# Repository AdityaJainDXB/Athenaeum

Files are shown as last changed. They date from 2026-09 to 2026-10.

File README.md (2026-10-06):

# Athenaeum

Open-source e-ink reader that downloads free books from Archive.org over Wi-Fi, takes notes on what you read, and even serves as a tiny offline viewer for NASA's public data. All on a single custom circuit board.

---

The idea

Since public domain books are free, you can also access The Internet Archive and Open Library with millions of these. NASA has tons of open data too – images from missions, the Astronomy Picture of the Day archive, the Artemis mission logs. But to be used, you need an internet connection, which isn't always available – weak school WiFi, no data plan, off the grid.

The Athenaeum, then, is a little battery powered piece of kit that solves this problem: when you're online, just sync up Athenaeum and it will take all of your books, your notes and a smattering of NASA's free open data with you as far as you go. And it's a multiple app device, too: it's designed as a little plug-in gadget and is capable of running multiple applications.

All of this – schematic, pcb and firmware – was really designed from scratch and is open source.

# It's basically a little computer with an e-ink display

The book reader is the first feature you get, not the only one it has. If you strip it away you end up with an ESP32-S3, a large e-ink display, Wi-Fi, an SD card, and buttons. The firmware is an app launcher, so creating a new feature (a flash card reader, a weather log, whatever) is a change to the firmware, not the design of the board. If you copy this board to create another project, you've already done the electronics.

What it does right now

1. Searches and downloads books from Archive.org / Open Library via Wi-Fi

- Reads them offline on the e-ink display (done) - exists a local library on microSD Would you like to comment? Post your comment or leave your feedback below: Name (required): Email (will not be published) (required): Comments: Submit" /> Submit DisableI want this answerAnswered.
- Allows you to save/flag notes associated with a book and page
- Features a "Space" app that takes NASA's Astronomy Picture of the Day for offline use
- Utilizes a rechargeable battery, charged via USB-C

Actually still on the to-do list that don't require phantom and name scanning: full EPUB rendering (currently just outputs plain text, which is what Archive.org's OCR files are, so this one is already working end to end for many books), APOD image in lieu of just the photo's caption, and a real scrollable book list rather than just "pop" the first file. All in firmware/README.md, as always.

The hardware

- ESP32-S3-WROOM-1 – Wi-Fi, USB native, everything runs on it
- Waveshare 7.5" e-Paper panel (800480), with a Waveshare Driver HAT plus a simple 8-pin header - we couldn't use the raw e-ink panels because they use an undocumented FPC connector, which makes designing a board around non-viable; this was the sane middle ground: still a fully custom PCB, just not re-inventing the display driver electronics as well
- MCP73831: Solves the USB power delivery problem by charging a single cell LiPo from a USB-C power source
- TLV70233 regulator - low standby current because this thing is going to need to sit in somebody's bag for weeks between charges
- microSD for the actual book/note storage
- 7 buttons: 5 for navigation, plus reset, and boot

Enclosure? None (this is designed to be used a bare board, with all the exposed components). The board outline is rounded off to prevent sharp edges, but there is no case concealing it.

Complete schematic & board files are located in /hardware.

# Pin map

| Signal | GPIO | | Signal | GPIO |

|---|---|---|---|---|

| EPD_CS | 10 | | Button: Up | 4 |

" /> Button: Up Button: Down | EPD_DC | 11 | | Button: Up | 5 |

| EPD_RST | 12 | | Button: Choose | 6 |

| EPD_BUSY | 13 | | Button: back | 7 |

Button: Menu 8 EPD_SCK 14

| EPD_MOSI | 15 | | SD CS | 16 |

| | | | SD MISO | 17 |

(SPI clock and MOSI are the same for display and SD card - separate CS lines are used for each, that is the correct design, not a shortcut.)

Repo layout

``

athenaeum/

hardware/

kicad/ KiCad project - schematic + PCB

gerbers/ Manufacturing files for JLCPCB

BOM.csv All parts list, with LCSC part numbers

firmware/ ESP32-S3 firmware (PlatformIO)

docs/ Build guide

`

Building one yourself

1. Upload the following data to the JLCPCB PCB Assembling: hardware/gerbers/ and hardware/BOM.csv
2. Flash the firmware - see firmware/README.md.
3. Insert the Waveshare Driver HAT + panel into the 8-pin header (J2).

Full walkthrough: docs/BUILDGUIDE.md.

Where things stand

- [x] Schematic - designed and verified
- [x] PCB - routed, DRC clean
- [x] Gerbers/BOM exported, ready for JLCPCB
- [x] Firmware - app launcher, Wi-Fi + Archive.org search/download, plain-text reading,
Scrollable book browser real on-device note-taking Space app
- [ ] EPUB parsing (accepts only plaintext atm)
- [ ] APOD image rendering (This is just text now)

- [ ] Demo video

Firmware limitations, stated plainly

This is a real, working firmware skeleton, not a finished article - worth being upfront

About exactly what it does and doesn't do so far:

- No EPUB support as yet. It only supports plain .txt files. Which just happens to be quite a lot of files.
Read already, as Archive.org's OCR'd texts come as .txt search
Download browse read works end to end for many public-domain books. EPUB actual The end Works The Bookshelf So when I teach my readers will lead to the works I read, in their works just to pass a great conversation, or even for passes… because I read in them.
(unzipping the container, parsing XHTML/CSS on-device) is an additional, substantial chunk.
 Of work, not yet started.
- All NASA APOD is text-only. It retrieves and displays the current day's title and date as well as the day's.
Explanation – but it is not the real photo. Rendering a true image on e-ink is
Download, JPEG-decoding, scaling, and dithering the image to 1-bit - has not even started.
- Character by character (single entry) picker, because there's no keyboard - it
Works, but writing anything that is of any length is slow. So a reasonably fast input scheme is the next step in design
 step.
- It hasn't been assembled and run on real hardware. It was written with great care against
The right libraries and the actual pcb pinout and there was a build missing too(ESP32).
Environment that I could use to test it during the development of this repo. Expect a standard
First-build debugging pass (a library version mismatch, an exact display-panel class
(name to confirm)and not a guaranteed 'perfect' first flash.

Full detail in firmware/README.md`.

License

Hardware (schematic, PCB): CERN-OHL-S v2. Firmware: MIT.

Thanks to

Open source projects Inkplate, Flick Book for previous E-ink reader, Waveshare for their Driver HAT docs, and Archive.org / Open Library for maintaining an open API.

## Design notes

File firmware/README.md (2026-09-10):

# Firmware

ESP32-S3 firmware, built on the Arduino core via PlatformIO.

## Structure

```
firmware/
├── platformio.ini          Build config, board target, library dependencies
└── src/
    ├── config.h             Pin definitions (matches the PCB design) + Wi-Fi credentials
    ├── buttons.h             Debounced button reading (Up/Down/Select/Back/Menu)
    ├── display.h              GxEPD2 wrapper for the Waveshare 7.5" panel
    ├── sd_storage.h            microSD init + book/notes/config directory setup
    ├── book_browser.h           Scrollable list of books on the SD card
    ├── reader.h                 Plain-text book reader with pagination
    ├── text_entry.h              On-device character-picker text entry for notes
    ├── notes.h                    Per-book note/highlight storage (JSON on SD)
    ├── space.h                     NASA APOD viewer
    ├── net/archive_api.h            Archive.org search + plain-text download client
    └── main.cpp                     App launcher tying everything together
```

## Building

1. Install [PlatformIO](https://platformio.org/) (CLI or the VS Code extension).
2. Fill in your Wi-Fi credentials in `src/config.h` - it ships with placeholder
   text (`YOUR_WIFI_SSID` etc.), so Wi-Fi-dependent features won't work until
   you swap those for your real network details.
3. Get a free NASA API key at [api.nasa.gov](https://api.nasa.gov) and set it in
   `src/space.h` (the shared `DEMO_KEY` works for development but is rate-limited).
4. `pio run -t upload` - flashes over USB-C (native USB on the ESP32-S3, no
   separate programmer needed).

## What's implemented

- App launcher menu (Reader / Space / Notes / Wi-Fi Sync), navigated with the 5 nav buttons
- **Book browser** - scrolls through every `.txt` file on the SD card, not just the first one found
- Plain-text book reading with pagination, from SD card
- **Real note-taking** - an on-device character picker (Up/Down to change letter, Select to
  add it, Back to delete, Menu to save) so notes are actually typed text, not a placeholder string
- NASA APOD: fetches and displays today's title, date, and explanation text
- Archive.org search (by query) and plain-text download of a result to SD

## Known scope limits (honest, not hidden)

- **EPUB rendering isn't implemented.** The reader and browser both work with plain `.txt`
  files, which conveniently covers Archive.org's `_djvu.txt` OCR derivative used by the
  download client - so search -> download -> browse -> read works end to end for a lot of
  public-domain texts already. True EPUB support means unzipping the container and parsing
  XHTML/CSS on-device, a real chunk of work on its own, tracked as a follow-up.
- **APOD image rendering isn't implemented.** Currently shows the day's title, date, and
  explanation as text only. The actual photo needs JPEG decode + resize + dither-to-1-bit
  for the e-ink panel, also tracked as a follow-up.
- **Text entry is slow by design** - a single-character-at-a-time picker is the realistic
  option on a 5-button device with no keyboard. It works, but writing a long note takes a
  while; a faster input scheme (e.g. T9-style grouping) is a reasonable future improvement.

## A note on testing

This firmware was written and reasoned through carefully, but it has not been compiled or
run on real hardware as part of putting this repository together - there was no ESP32 or
build environment available to do that. Treat the first build as a normal first build:
expect to work through a handful of small compile issues (a library version mismatch, an
exact class name for your specific panel revision) rather than a flawless first flash.
The structure and logic are sound; the fine details of a first bring-up are still yours to
work through.

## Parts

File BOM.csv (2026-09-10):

Designator | Value | Footprint | LCSC Part | Description | Approx Unit Cost (USD) | Qty
U1 | ESP32-S3-WROOM-1 | RF_Module:ESP32-S3-WROOM-1 | C2913198 | ESP32-S3 Wi-Fi/BLE module 8MB flash | ~2.50 | 1
U2 | MCP73831-2-OT | Package_TO_SOT_SMD:SOT-23-5 | C424093 | LiPo linear charge management IC (4.2V) | ~0.15 | 1
U3 | TLV70233_SOT23-5 | Package_TO_SOT_SMD:SOT-23-5 | C110287 | 3.3V low-IQ LDO regulator | ~0.20 | 1
J1 | USB_C_Receptacle_USB2.0_14P | Connector_USB:USB_C_Receptacle_GCT_USB4085 |  | USB-C receptacle (power + data) | ~0.30 | 1
J2 | Conn_01x08 | Connector_PinHeader_2.54mm:PinHeader_1x08_P2.54mm_Vertical |  | 8-pin header to e-Paper Driver HAT | ~0.10 | 1
J3 | Micro_SD_Card_Det1 | Connector_Card:microSD_HC_Molex_47219-2001 |  | microSD card socket | ~0.40 | 1
BT1 | Battery_Cell | Connector_JST:JST_PH_S2B-PH-K_1x02_P2.00mm_Horizontal |  | JST-PH 2-pin battery connector | ~0.10 | 1
D1 | LED | LED_SMD:LED_0603_1608Metric |  | Charging status LED | ~0.02 | 1
C1 | 100nF | Capacitor_SMD:C_0603_1608Metric |  | Decoupling capacitor | ~0.01 | 1
C2 | 10uF | Capacitor_SMD:C_0603_1608Metric |  | Bulk decoupling capacitor | ~0.02 | 1
R1 | 10k | Resistor_SMD:R_0603_1608Metric |  | Boot (GPIO0) pull-up | ~0.01 | 1
R2 | 10k | Resistor_SMD:R_0603_1608Metric |  | Reset (EN) pull-up | ~0.01 | 1
R3 | 5.1k | Resistor_SMD:R_0603_1608Metric |  | USB-C CC1 pull-down | ~0.01 | 1
R4 | 5.1k | Resistor_SMD:R_0603_1608Metric |  | USB-C CC2 pull-down | ~0.01 | 1
R5 | 2k | Resistor_SMD:R_0603_1608Metric |  | Charge current set (PROG) | ~0.01 | 1
R6 | 1k | Resistor_SMD:R_0603_1608Metric |  | Status LED current limit | ~0.01 | 1
R7 | 10k | Resistor_SMD:R_0603_1608Metric |  | Button pull-up (Up) | ~0.01 | 1
R8 | 10k | Resistor_SMD:R_0603_1608Metric |  | Button pull-up (Down) | ~0.01 | 1
R9 | 10k | Resistor_SMD:R_0603_1608Metric |  | Button pull-up (Menu) | ~0.01 | 1
R10 | 10k | Resistor_SMD:R_0603_1608Metric |  | Button pull-up (Back) | ~0.01 | 1
R11 | 10k | Resistor_SMD:R_0603_1608Metric |  | Button pull-up (Select) | ~0.01 | 1
SW1 | SW_Push | Button_Switch_THT:SW_PUSH_6mm |  | Boot button | ~0.05 | 1
SW2 | SW_Push | Button_Switch_THT:SW_PUSH_6mm |  | Reset button | ~0.05 | 1
SW3 | SW_Push | Button_Switch_THT:SW_PUSH_6mm |  | Nav button: Up | ~0.05 | 1
SW4 | SW_Push | Button_Switch_THT:SW_PUSH_6mm |  | Nav button: Down | ~0.05 | 1
SW5 | SW_Push | Button_Switch_THT:SW_PUSH_6mm |  | Nav button: Menu | ~0.05 | 1
SW6 | SW_Push | Button_Switch_THT:SW_PUSH_6mm |  | Nav button: Back | ~0.05 | 1
SW7 | SW_Push | Button_Switch_THT:SW_PUSH_6mm |  | Nav button: Select | ~0.05 | 1
Off-board items (not part of PCB assembly order):
Item | Description | Approx Cost (USD) | Qty
Waveshare 7.5" e-Paper panel (800x480 mono) | Main display | ~35-45 | 1
Waveshare Universal e-Paper Driver HAT | FPC-to-header display adapter | ~10 | 1
Single-cell LiPo battery (JST-PH connector) | Power source - capacity TBD based on enclosure size | ~5-8 | 1
Note: unit costs are approximate JLCPCB/LCSC catalog estimates as of design time and should be
re-verified at checkout | since component pricing and stock fluctuate. PCB fabrication and assembly
service fees (setup | extended-part fees | shipping) are separate from per-component costs above.

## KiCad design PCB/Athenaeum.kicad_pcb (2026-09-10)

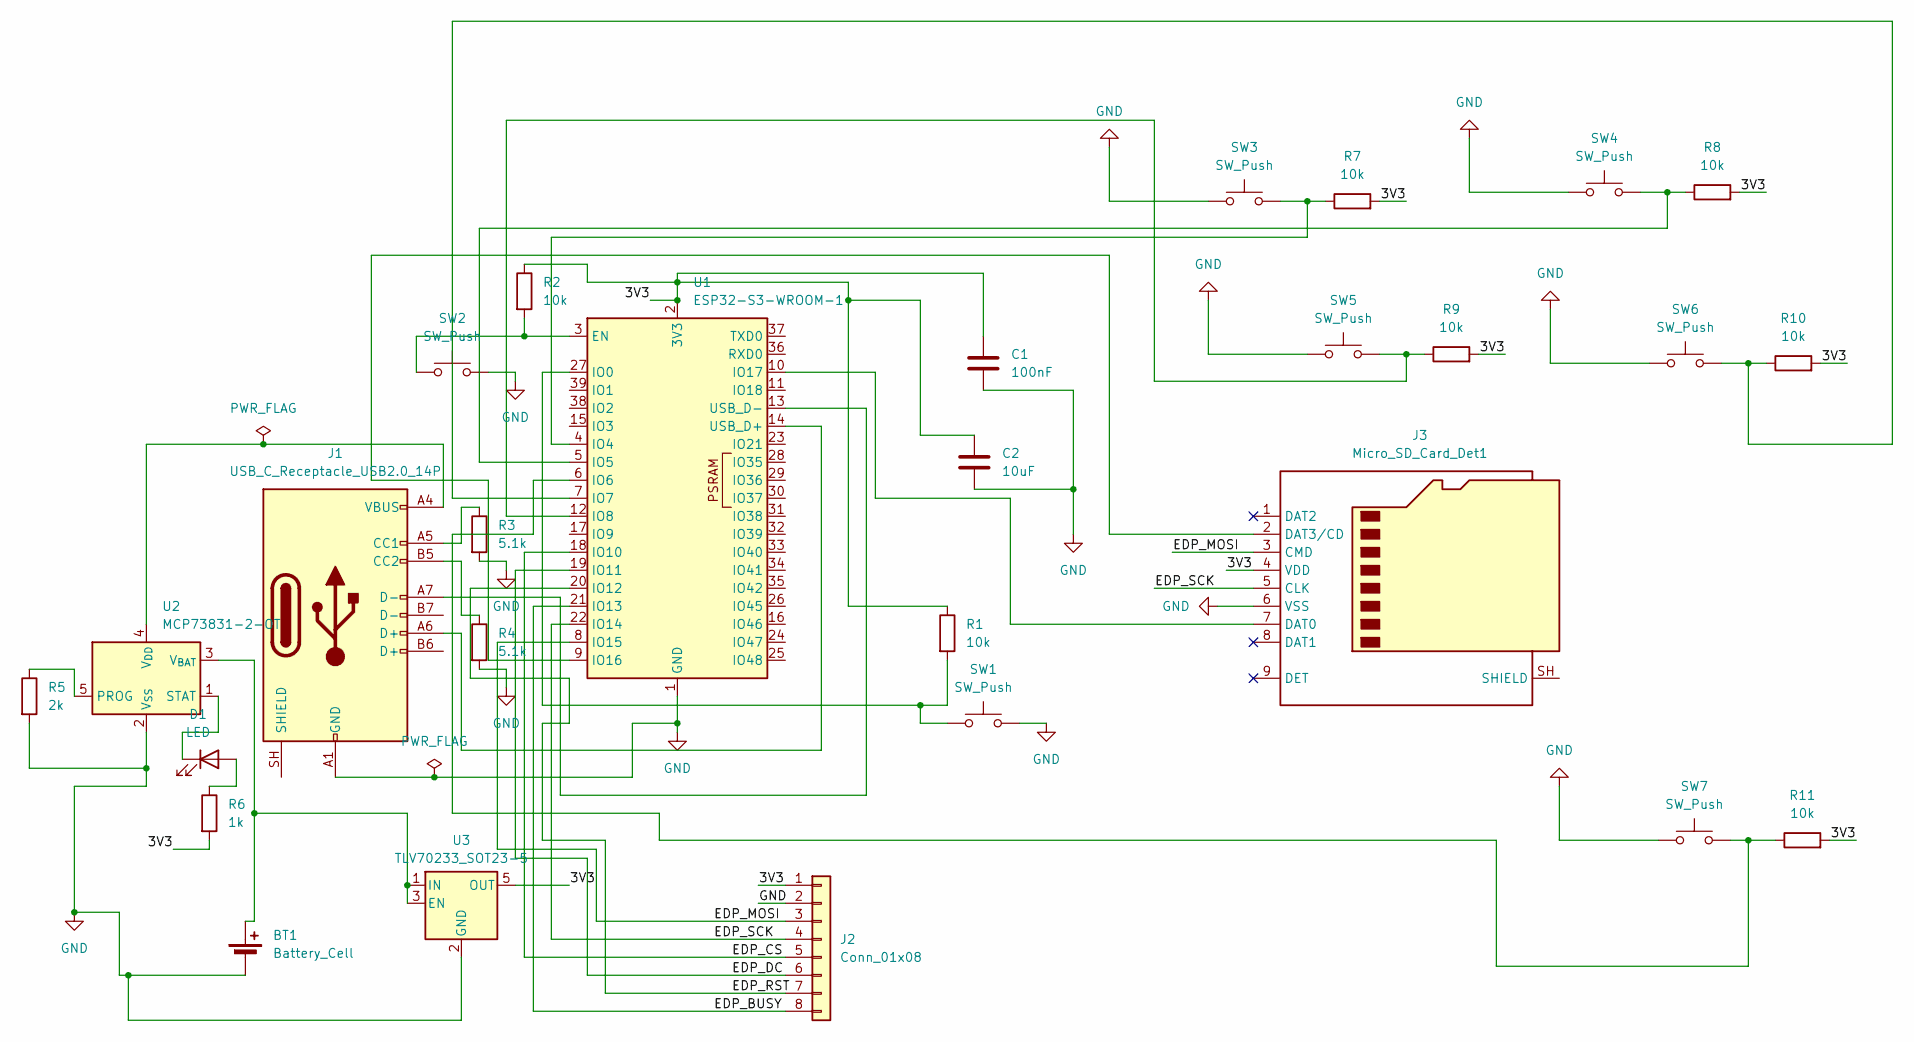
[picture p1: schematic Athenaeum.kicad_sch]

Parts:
BT1: Battery_Cell; JST_PH_S2B-PH-K_1x02_P2.00mm_Horizontal
C1: 100nF; C_0603_1608Metric
C2: 10uF; C_0603_1608Metric
D1: LED; LED_0603_1608Metric
J1: USB_C_Receptacle_USB2.0_14P; USB_C_Receptacle_GCT_USB4085
J2: Conn_01x08; PinHeader_1x08_P2.54mm_Vertical
J3: Micro_SD_Card_Det1; microSD_HC_Molex_47219-2001
R1, R2, R7, R8, R9, R10, R11: 10k; R_0603_1608Metric
R3, R4: 5.1k; R_0603_1608Metric
R5: 2k; R_0603_1608Metric
R6: 1k; R_0603_1608Metric
SW1, SW2, SW3, SW4, SW5, SW6, SW7: SW_Push; SW_PUSH_6mm
U1: ESP32-S3-WROOM-1
U2: MCP73831-2-OT; SOT-23-5
U3: TLV70233_SOT23-5; SOT-23-5

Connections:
/3V3: C1.1, C2.1, J2.1, J3.4 (VDD), R1.1, R2.1, R6.2, R7.2, R8.2, R9.2, R10.2, R11.2, U1.2 (3V3), U3.5 (OUT)
/EDP_BUSY: J2.8, U1.21 (IO13)
/EDP_CS: J2.5, U1.18 (IO10)
/EDP_DC: J2.6, U1.19 (IO11)
/EDP_MOSI: J2.3, J3.3 (CMD), U1.8 (IO15)
/EDP_RST: J2.7, U1.20 (IO12)
/EDP_SCK: J2.4, J3.5 (CLK), U1.22 (IO14)
GND: BT1.2 (-), C1.2, C2.2, J1.A1 (GND), J1.A12 (GND), J1.B1 (GND), J1.B12 (GND), J2.2, J3.6 (VSS), R3.2, R4.2, R5.2, SW1.2, SW2.2, SW3.1, SW4.1, SW5.1, SW6.1, SW7.1, U1.1 (GND), U1.40 (GND), U1.41 (GND), U2.2 (V_{SS}), U3.2 (GND)
unnamed: BT1.1 (+), U2.3 (V_{BAT}), U3.1 (IN), U3.3 (EN)
unnamed: D1.2 (A), R6.1
unnamed: D1.1 (K), U2.1 (STAT)
unnamed: J1.A5 (CC1), R3.1
unnamed: J1.B5 (CC2), R4.1
unnamed: J3.7 (DAT0), U1.10 (IO17)
unnamed: J3.2 (DAT3/CD), U1.9 (IO16)
unnamed: R2.2, SW2.1, U1.3 (EN)
unnamed: R1.2, SW1.1, U1.27 (IO0)
unnamed: R7.1, SW3.2, U1.4 (IO4)
unnamed: R8.1, SW4.2, U1.5 (IO5)
unnamed: R11.1, SW7.2, U1.6 (IO6)
unnamed: R10.1, SW6.2, U1.7 (IO7)
unnamed: R9.1, SW5.2, U1.12 (IO8)
unnamed: J1.A6 (D+), U1.14 (USB_D+)
unnamed: J1.A7 (D-), U1.13 (USB_D-)
unnamed: R5.1, U2.5 (PROG)
unnamed: J1.A4 (VBUS), J1.A9 (VBUS), J1.B4 (VBUS), J1.B9 (VBUS), U2.4 (V_{DD})

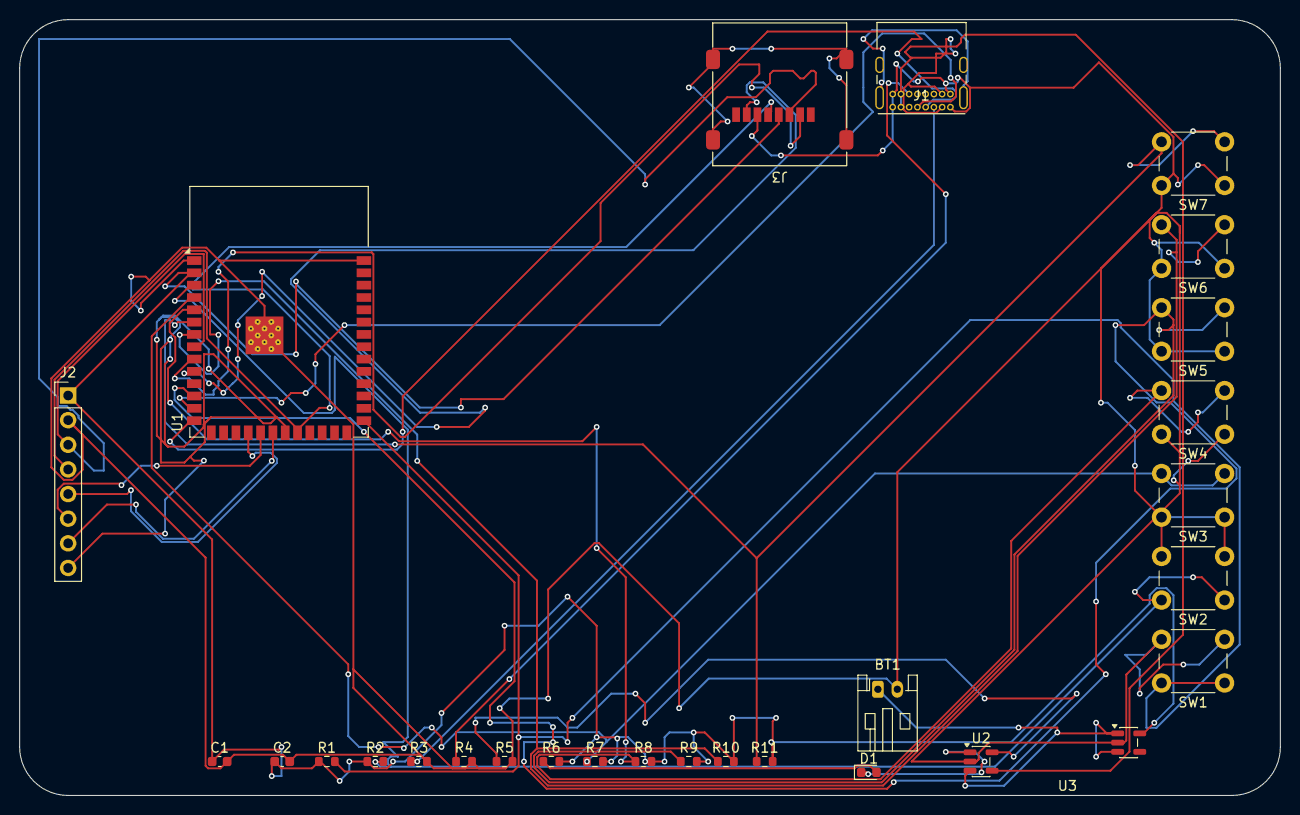
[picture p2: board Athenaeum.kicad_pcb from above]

Board: 2 copper layers, 130.0 x 80.0 mm, 28 parts (0 on the bottom side), 26 nets.

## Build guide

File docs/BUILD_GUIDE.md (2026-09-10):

# Build Guide

## 1. Get the PCB made

1. Open `hardware/kicad/Athenaeum.kicad_pro` in KiCad to review the design, or go straight to manufacturing.
2. Upload the Gerber ZIP from `hardware/gerbers/` to [JLCPCB](https://jlcpcb.com).
3. On JLCPCB's order page, enable **PCB Assembly (PCBA)** and upload `hardware/BOM.csv` and the matching CPL (component placement) file from `hardware/gerbers/`.
4. Confirm the ESP32-S3-WROOM-1, MCP73831, and TLV70233 all matched correctly against JLCPCB's parts library (they're listed as Basic Parts with LCSC numbers in the BOM) — connectors and switches will show as Extended Parts, which is expected.
5. Order.

## 2. Get the display

1. Order a **Waveshare 7.5" e-Paper panel (800×480, monochrome)**.
2. Order a **Waveshare Universal e-Paper Driver HAT** separately.
3. Connect the panel's FPC cable into the Driver HAT's ZIF socket.
4. The Driver HAT's 8-pin output connects directly into J2 on the Athenaeum board.

## 3. Flash the firmware

See [`firmware/README.md`](../firmware/README.md) for toolchain setup and flashing instructions.

## 4. Assemble

1. Mount the assembled PCB somewhere secure — remember, no enclosure by design, so handle it like any exposed board.
2. Connect the Driver HAT/panel assembly to J2.
3. Connect a single-cell LiPo battery to the JST-PH connector (BT1) — mind polarity.
4. Insert a microSD card into J3.
5. Power on via USB-C.

## Known constraints / design notes

- The ESP32-S3 module's onboard antenna keep-out zone is kept clear of copper and components on the PCB — do not modify layout in that region without preserving the clearance.
- SPI bus (SCK/MOSI) is shared between the display and microSD card, each with an independent chip-select line — this is intentional, not a routing shortcut.
- The two mirrored USB-C D+/D- pins (for cable reversibility) are intentionally left unconnected on one side per pair — this is correct per the USB-C spec, not a missing connection.

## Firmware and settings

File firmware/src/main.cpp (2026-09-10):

#include <Arduino.h>
#include <WiFi.h>
#include <SD.h>
#include "config.h"
#include "buttons.h"
#include "display.h"
#include "sd_storage.h"
#include "notes.h"
#include "reader.h"
#include "space.h"
#include "book_browser.h"
#include "text_entry.h"
#include "net/archive_api.h"

// --- App launcher state ---
enum class App { MENU, BROWSER, READER, NOTE_ENTRY, SPACE, NOTES };
App currentApp = App::MENU;
int menuSelection = 0;
const char* menuItems[] = { "Reader", "Space", "Notes", "Wi-Fi Sync" };
const int menuItemCount = 4;

Buttons buttons;
Display display;
Storage storage;
Notes notes;
Reader reader;
SpaceApp spaceApp;
ArchiveClient archive;
BookBrowser bookBrowser;
TextEntry textEntry;

bool wifiConnected = false;

void connectWiFi() {
    WiFi.begin(WIFI_SSID, WIFI_PASSWORD);
    unsigned long start = millis();
    while (WiFi.status() != WL_CONNECTED && millis() - start < 10000) {
        delay(200);
    }
    wifiConnected = (WiFi.status() == WL_CONNECTED);
}

void drawMenu() {
    display.fullRefresh([](auto& epd) {
        epd.setFont(&FreeSansBold12pt7b);
        epd.setCursor(10, 30);
        epd.print("Athenaeum");

        epd.setFont(&FreeSans9pt7b);
        for (int i = 0; i < menuItemCount; i++) {
            epd.setCursor(30, 90 + i * 40);
            if (i == menuSelection) epd.print("> ");
            else epd.print("  ");
            epd.print(menuItems[i]);
        }
    });
}

// ---- Menu ----
void openSelectedApp() {
    switch (menuSelection) {
        case 0:
            bookBrowser.refresh();
            currentApp = App::BROWSER;
            bookBrowser.render(display);
            break;
        case 1:
            currentApp = App::SPACE;
            if (wifiConnected && spaceApp.fetchToday()) {
                spaceApp.render(display);
            }
            break;
        case 2:
            currentApp = App::NOTES;
            break;
        case 3:
            connectWiFi();
            drawMenu();
            break;
    }
}

void handleMenuInput(Button b) {
    switch (b) {
        case Button::UP:
            menuSelection = (menuSelection - 1 + menuItemCount) % menuItemCount;
            drawMenu();
            break;
        case Button::DOWN:
            menuSelection = (menuSelection + 1) % menuItemCount;
            drawMenu();
            break;
        case Button::SELECT:
            openSelectedApp();
            break;
        default:
            break;
    }
}

// ---- Book browser ----
void handleBrowserInput(Button b) {
    switch (b) {
        case Button::UP:
            bookBrowser.moveUp();
            bookBrowser.render(display);
            break;
        case Button::DOWN:
            bookBrowser.moveDown();
            bookBrowser.render(display);
            break;
        case Button::SELECT:
            if (!bookBrowser.empty() && reader.open(bookBrowser.selectedPath())) {
                currentApp = App::READER;
                reader.renderPage(display);
            }
            break;
        case Button::BACK:
            currentApp = App::MENU;
            drawMenu();
            break;
        default:
            break;
    }
}

// ---- Reader ----
void handleReaderInput(Button b) {
    switch (b) {
        case Button::DOWN:
            reader.nextPage(display);
            break;
        case Button::UP:
            reader.prevPage(display);
            break;
        case Button::BACK:
            reader.close();
            currentApp = App::MENU;
            drawMenu();
            break;
        case Button::SELECT:
            // Open real text entry instead of saving a fixed placeholder
            textEntry.reset();
            currentApp = App::NOTE_ENTRY;
            textEntry.render(display);
            break;
        default:
            break;
    }
}

// ---- Note text entry ----
void handleNoteEntryInput(Button b) {
    switch (b) {
        case Button::UP:
            textEntry.charUp();
            textEntry.render(display);
            break;
        case Button::DOWN:
            textEntry.charDown();
            textEntry.render(display);
            break;
        case Button::SELECT:
            textEntry.confirmChar();
            textEntry.render(display);
            break;
        case Button::BACK:
            textEntry.backspace();
            textEntry.render(display);
            break;
        case Button::MENU:
            // Save and return to the reader
            if (textEntry.text().length() > 0) {
                notes.add(reader.bookId(), reader.currentPage(), textEntry.text());
            }
            currentApp = App::READER;
            reader.renderPage(display);
            break;
    }
}

void handleGlobalBack(Button b) {
    if (b == Button::BACK) {
        currentApp = App::MENU;
        drawMenu();
    }
}

void setup() {
    Serial.begin(115200);
    buttons.begin();
    display.begin();

    if (!storage.begin()) {
        display.fullRefresh([](auto& epd) {
            epd.setFont(&FreeSans9pt7b);
            epd.setCursor(10, 30);
            epd.print("SD card not found - insert a card and restart.");
        });
        return;
    }

    drawMenu();
}

void loop() {
    Button b = buttons.poll();
    if (b == Button::NONE) {
        delay(20);
        return;
    }

    switch (currentApp) {
        case App::MENU:
            handleMenuInput(b);
            break;
        case App::BROWSER:
            handleBrowserInput(b);
            break;
        case App::READER:
            handleReaderInput(b);
            break;
        case App::NOTE_ENTRY:
            handleNoteEntryInput(b);
            break;
        case App::SPACE:
        case App::NOTES:
            handleGlobalBack(b);
            break;
    }
}

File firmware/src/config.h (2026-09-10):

#pragma once

// ---- e-Paper display (via Waveshare Driver HAT, through J2) ----
#define PIN_EPD_CS    10
#define PIN_EPD_DC    11
#define PIN_EPD_RST   12
#define PIN_EPD_BUSY  13
#define PIN_EPD_SCK   14
#define PIN_EPD_MOSI  15
// Display is write-only over this driver HAT interface - no MISO needed

// ---- microSD card (shares SCK/MOSI with the display, own CS + dedicated MISO) ----
#define PIN_SD_CS     16
#define PIN_SD_MISO   17

// ---- Navigation buttons (active LOW, external 10k pull-ups) ----
#define PIN_BTN_UP      4
#define PIN_BTN_DOWN    5
#define PIN_BTN_SELECT  6
#define PIN_BTN_BACK    7
#define PIN_BTN_MENU    8

// ---- Battery voltage sense (optional, via ADC) ----
#define PIN_BATT_ADC    9

// ---- Display geometry (Waveshare 7.5" panel) ----
#define EPD_WIDTH   800
#define EPD_HEIGHT  480

// ---- Wi-Fi credentials (fill in, or move to a non-committed secrets.h) ----
#define WIFI_SSID     "YOUR_WIFI_SSID"
#define WIFI_PASSWORD "YOUR_WIFI_PASSWORD"

// ---- SD card paths ----
#define SD_BOOKS_DIR   "/books"
#define SD_NOTES_DIR   "/notes"
#define SD_CONFIG_DIR  "/config"

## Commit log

2026-09-10 Initial commit: schematic, PCB, firmware, BOM, docs
    [Athenaeum-B_Cu.gbr, Athenaeum-B_Mask.gbr, Athenaeum-B_Paste.gbr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]
2026-09-10 Add BOM.csv to repo root for funding form
    [BOM.csv]
